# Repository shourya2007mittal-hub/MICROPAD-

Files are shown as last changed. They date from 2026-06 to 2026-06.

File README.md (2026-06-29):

# MICROPAD-



I  built a updated macro pad with 9 switches an 0.91 inch Display , a rotor encoder through which I can change between the layers and one RGB LED per switch , It will be  use wireless connection and will use Xiao nrf52840 as the main microcontroller.

## Features

- Base on Xiao NRF Module
- Has per switch LED
- Works wirelessly and has a Battery built in
- Has 9 Switch and 3 Different Layers to switch onto

# Bill of Materials (BOM)

This document contains the list of all components required for the project, including quantities, estimated prices, and direct purchase links.

## Components

| Item | Quantity | Price (USD) | Purchase Link |
|---|---|---:|---|
| PCB + Shipping | - | 18.72 | https://jlcpcb.com |
| SK6812 Mini-E RGB | 1 Pack | 13.19 | https://www.desertcart.in/products/713547616-50pcs-sk6812-mini-e-rgb-similar-with-ws2812b-sk6812-3228 |
| Mini SPDT Slide Switch (+ Shipping) | Pack of 3 | 1.64 | https://www.amazon.in/gp/product/B0B434R6QF/ref=ox_sc_act_image_1?smid=A2JDRZEGU1IDE2&psc=1 |
| Blank DSA Keycaps | 2 Sets of 5 | 2.00 | https://meckeys.com/shop/accessories/keyboard-accessories/keycaps/blank/blank-dsa-keycaps-1u/ |
| Kailh Hot-Swap Sockets | 2 Packs of 5 | 1.65 | https://meckeys.com/shop/accessories/keyboard-accessories/key-switches/kailh-hot-swap-socket/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 |
| Gateron Optical Switches | 1 Pack of 10 | 4.50 | https://meckeys.com/shop/accessories/keyboard-accessories/key-switches/gateron-optical-switch-pack/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 |
| Meckeys Shipping | - | 1.10 | https://meckeys.com |
| 450mAh 3.7V LiPo Battery | 1 | 1.70 | https://robocraze.com/products/450mah-3-7v-lipo-rechargeable-battery?variant=51440287219936 |
| Rotary Encoder Module | 1 | 0.69 | https://robocraze.com/products/rotary-encoder-module?variant=40193048543385 |
| 0.91" OLED Display Module | 1 | 1.58 | https://robocraze.com/products/0-91-inch-blue-oled-display-module?variant=40194383413401 |
| Seeed Studio XIAO nRF52840 | 1 | 12.16 | https://robocraze.com/products/seeed-studio-xiao-nrf52840-development-board-supports-bluetooth-5-0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 |

## Estimated Cost

| Description | Amount (USD) |
|---|---:|
| **Total Estimated Cost** | **58.93** |

### Schematic



###  PCB Design




### 3D Design





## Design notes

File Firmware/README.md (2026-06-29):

# XIAO nRF52840 3-Layer Macropad Firmware

## Pin Allocation (From Schematic)
- **Rows:** R1 -> D0, R2 -> D1, R3 -> D2
- **Columns:** C1 -> D3, C2 -> D6, C3 -> D8
- **I2C Display:** SDA -> D4, SCL -> D5
- **Encoder:** A1 -> D9, B1 -> D10
- **LED Indicator:** LED -> D5 (Shared pin configuration)

## Features
1. **Boot Mode Condition:** Hold down Key 1 (Row 1, Column 1) during startup to enter **Input Device Mode** (USB HID Keyboard). Powering on without holding the key sets it to **Output Device Mode**.
2. **Layer Switching:** Turn the rotary encoder to cycle seamlessly through 3 structural key layers.
3. **OLED Status:** Displays the current operating mode and active layer in real-time.

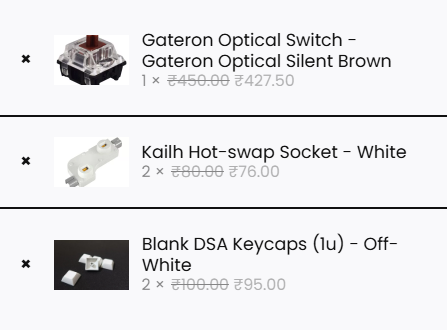
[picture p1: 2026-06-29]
Screen-Shot/Screenshot 2026-06-30 000758.png

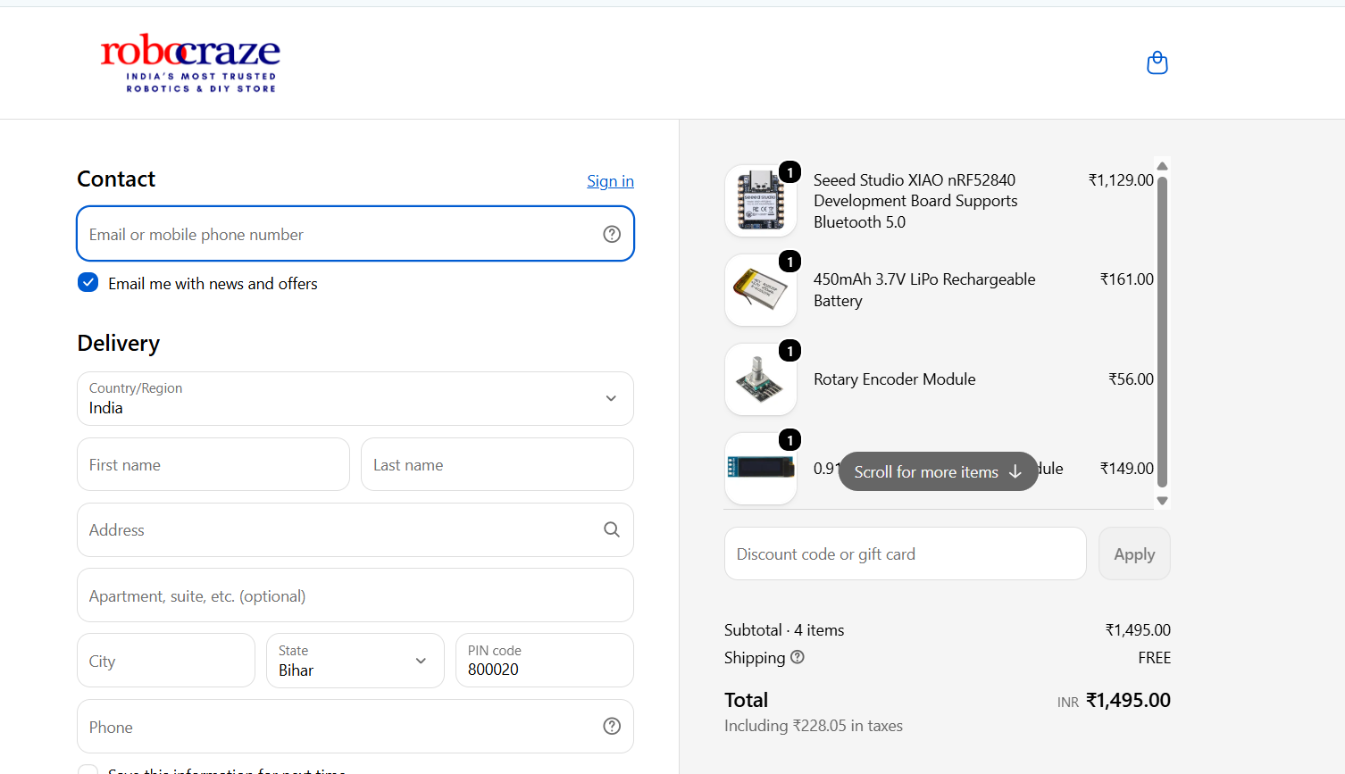
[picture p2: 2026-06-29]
Screen-Shot/Screenshot 2026-06-30 002320.png

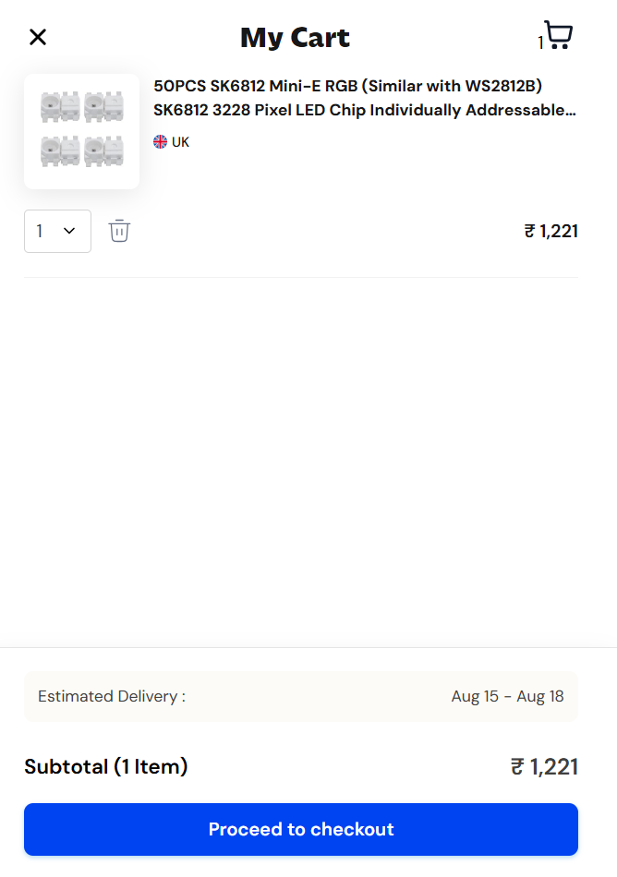
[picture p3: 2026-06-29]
Screen-Shot/Screenshot 2026-06-30 001117.png

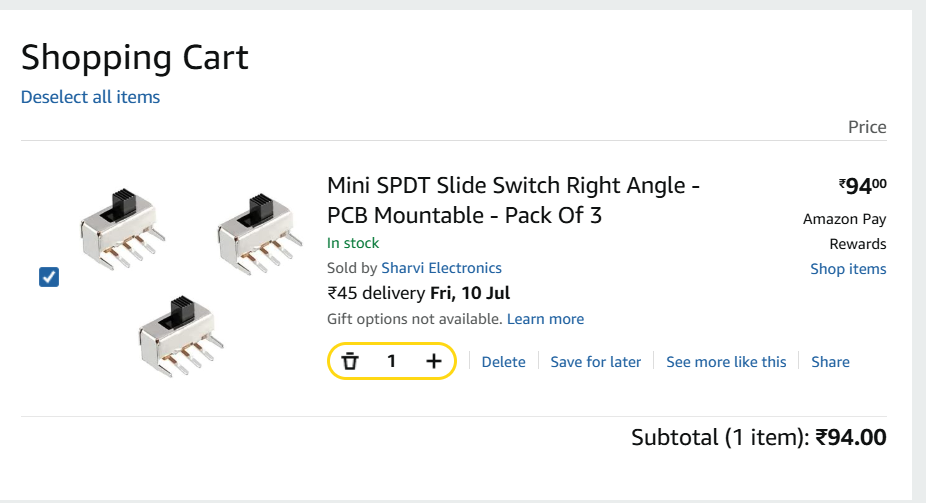
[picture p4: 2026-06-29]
Screen-Shot/Screenshot 2026-06-30 000644.png

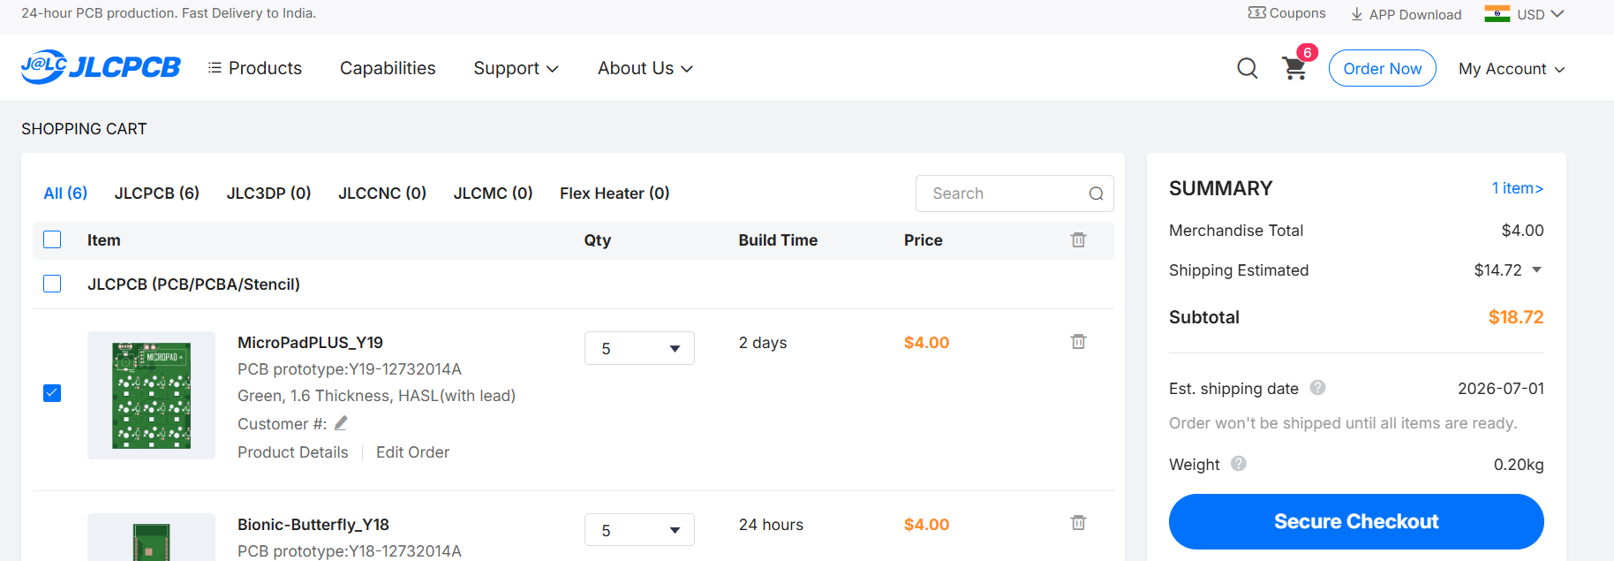
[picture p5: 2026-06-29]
Screen-Shot/Screenshot 2026-06-29 235157.png

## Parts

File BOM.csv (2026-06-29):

Item | Quantity | Price | Source
PCB + Shipping | - | 4+14.72=18.72 | JLCPCB
SK6812 Mini-E RGB | 1 PACK | 13.19 | https://www.desertcart.in/products/713547616-50pcs-sk6812-mini-e-rgb-similar-with-ws2812b-sk6812-3228
Mini SPDT Slide Switch + shipping | Pack of (3) | 1.64 | https://www.amazon.in/gp/product/B0B434R6QF/ref=ox_sc_act_image_1?smid=A2JDRZEGU1IDE2&psc=1
Keycaps | 2 set of 5 | 2 | https://meckeys.com/shop/accessories/keyboard-accessories/keycaps/blank/blank-dsa-keycaps-1u/
Hot-swap | 2 Pack of 5 | 1.65 | https://meckeys.com/shop/accessories/keyboard-accessories/key-switches/kailh-hot-swap-socket/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
Switch | 1 Pack of 10 | 4.5 | https://meckeys.com/shop/accessories/keyboard-accessories/key-switches/gateron-optical-switch-pack/
Meckeys shipping | - | 1.1 | meckey.com
450mAh 3.7V LiPo Battery | 1 | 1.7 | https://robocraze.com/products/450mah-3-7v-lipo-rechargeable-battery?variant=51440287219936
Rotary Encoder | 1 | .69 | https://robocraze.com/products/rotary-encoder-module?variant=40193048543385
0.91 inch OLED Screen | 1 | 1.58 | https://robocraze.com/products/0-91-inch-blue-oled-display-module?variant=40194383413401
Seeed Studio XIAO nRF52840 | 1 | 12.16 | https://robocraze.com/products/seeed-studio-xiao-nrf52840-development-board-supports-bluetooth-5-0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

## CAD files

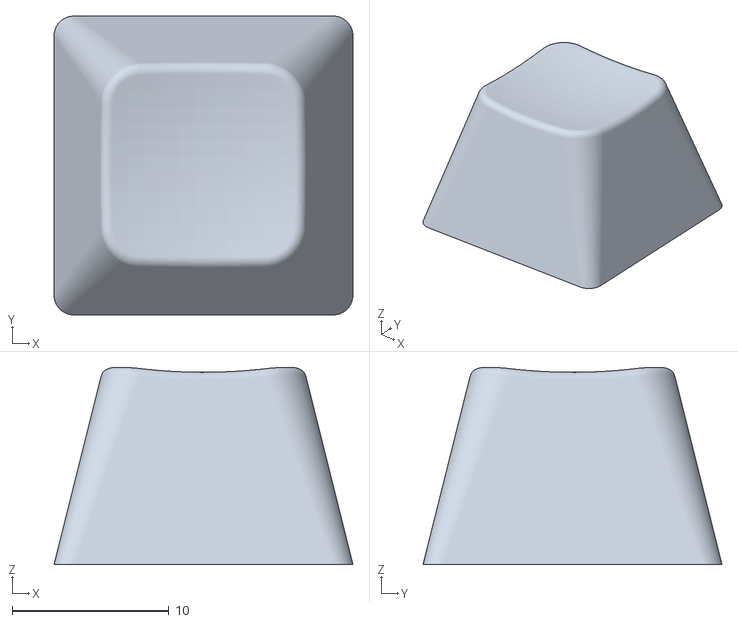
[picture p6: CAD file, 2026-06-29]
Production/CAD/KeyCap.stl
19.0 x 19.0 x 12.6

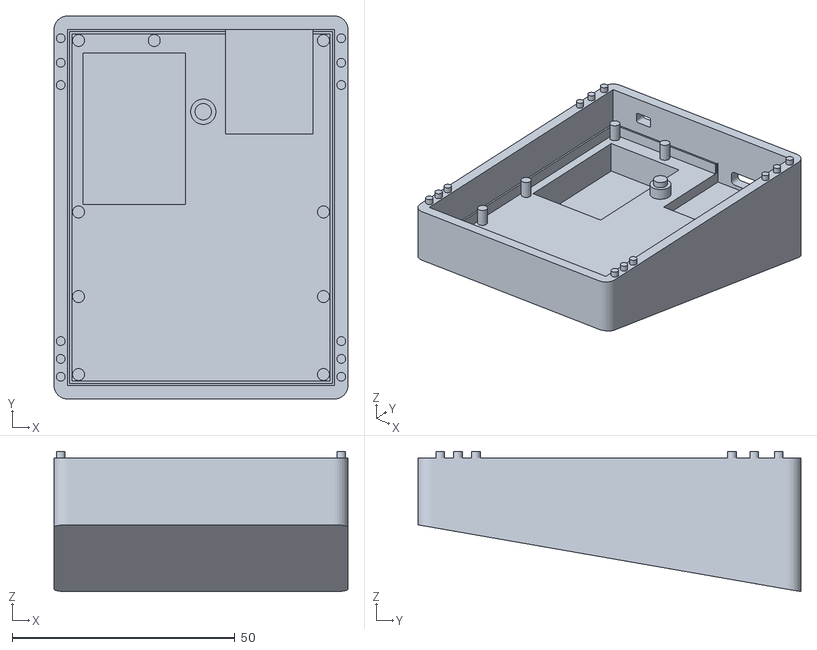
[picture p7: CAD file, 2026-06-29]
Production/CAD/Bottom-Base.stl
66.0 x 86.0 x 31.5

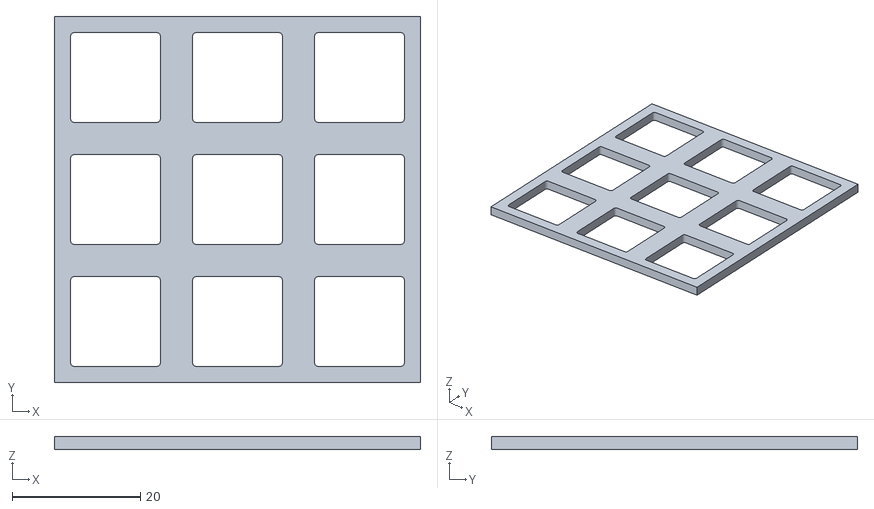
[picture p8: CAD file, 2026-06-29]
Production/CAD/Switch Holder.stl
57.1 x 57.1 x 2.00

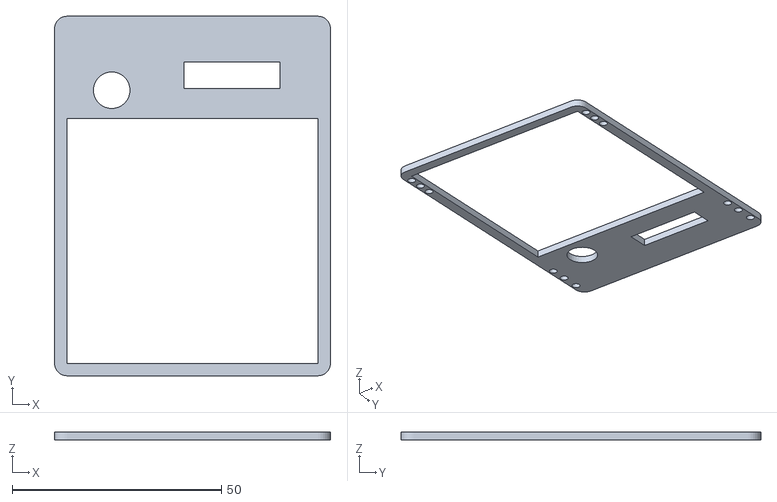
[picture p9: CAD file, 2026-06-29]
Production/CAD/Top-Cover.stl
66.0 x 86.0 x 2.00

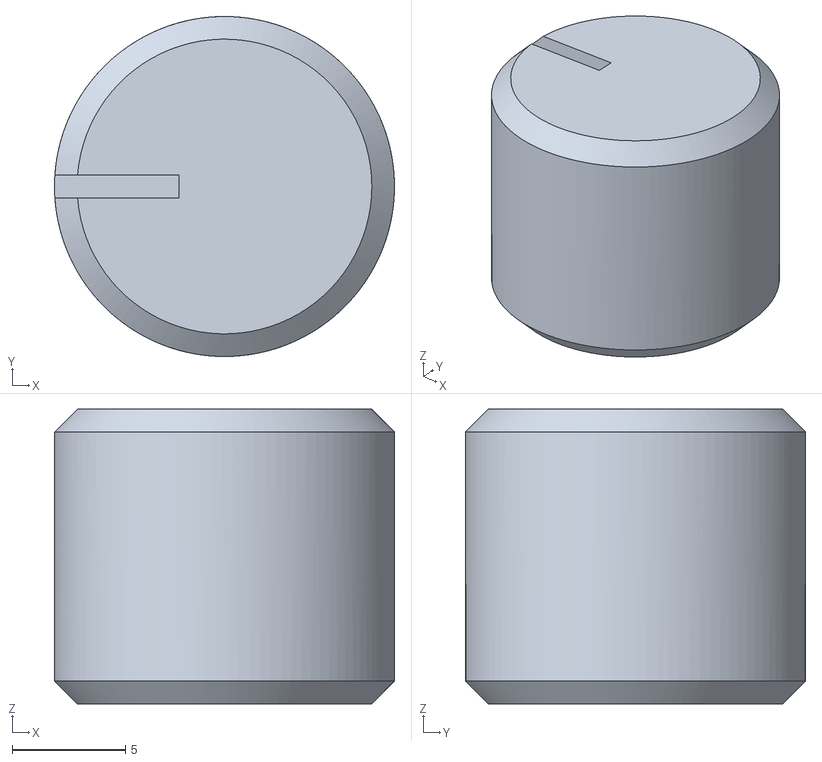
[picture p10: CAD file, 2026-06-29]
Production/CAD/rotarydial.stl
15.0 x 15.0 x 13.0

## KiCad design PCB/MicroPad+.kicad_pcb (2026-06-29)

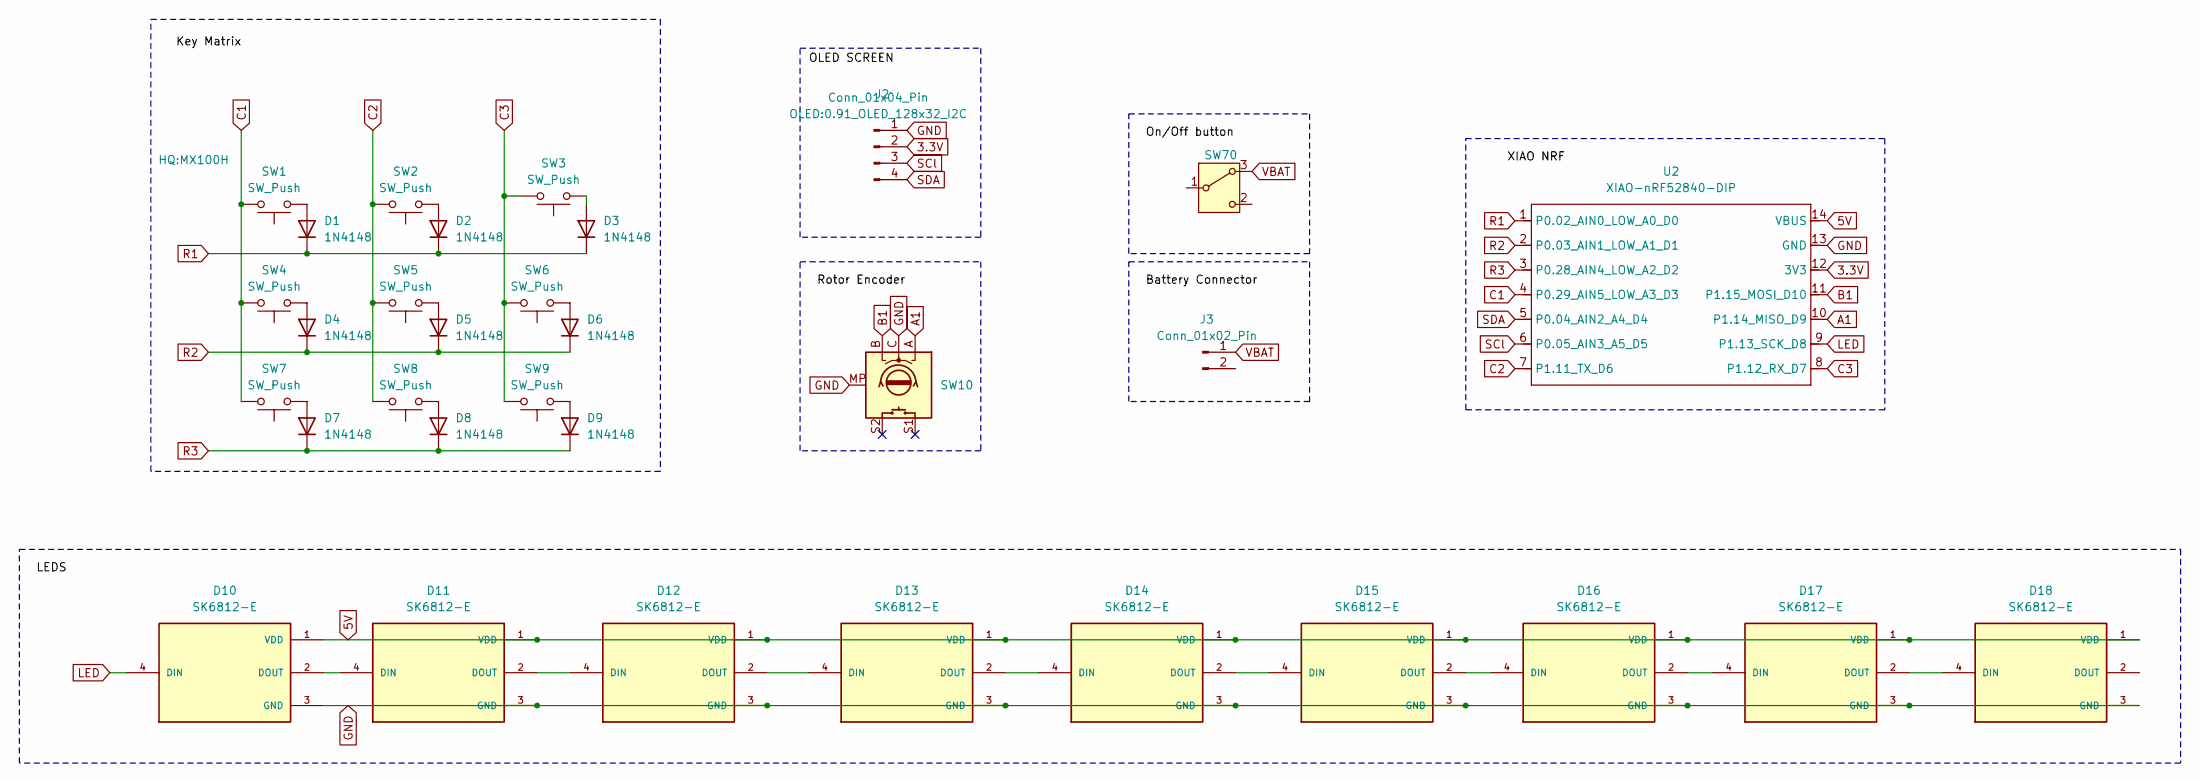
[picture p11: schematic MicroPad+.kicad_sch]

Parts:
D1, D2, D3, D4, D5, D6, D7, D8, D9: 1N4148; D_DO-35_SOD27_P7.62mm_Horizontal
D10, D11, D12, D13, D14, D15, D16, D17, D18: SK6812-E; LED_SK6812-E; PARTREV 2
J2: Conn_01x04_Pin; 0.91_OLED_128x32_I2C
J3: Conn_01x02_Pin; AMASS_XT30U-F_1x02_P5.0mm_Vertical
SW1, SW2, SW3, SW4, SW5, SW6, SW7, SW8, SW9: SW_Push; MX100H
SW10: RotaryEncoder_Switch_MP; RotaryEncoder_Alps_EC11E-Switch_Vertical_H20mm
SW70: SW_Wuerth_450301014042; SW_Slide_SPDT_Angled_CK_OS102011MA1Q
U2: XIAO-nRF52840-DIP; XIAO-nRF52840-SMD

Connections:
3.3V: J2.2, U2.12 (3V3)
5V: D10.1 (VDD), D11.1 (VDD), D12.1 (VDD), D13.1 (VDD), D14.1 (VDD), D15.1 (VDD), D16.1 (VDD), D17.1 (VDD), D18.1 (VDD), U2.14 (VBUS)
A1: SW10.A, U2.10 (P1.14_MISO_D9)
B1: SW10.B, U2.11 (P1.15_MOSI_D10)
C1: SW1.2, SW4.2, SW7.2, U2.4 (P0.29_AIN5_LOW_A3_D3)
C2: SW2.2, SW5.2, SW8.2, U2.7 (P1.11_TX_D6)
C3: SW3.2, SW6.2, SW9.2, U2.8 (P1.12_RX_D7)
GND: D10.3 (GND), D11.3 (GND), D12.3 (GND), D13.3 (GND), D14.3 (GND), D15.3 (GND), D16.3 (GND), D17.3 (GND), D18.3 (GND), J2.1, SW10.C, SW10.MP, U2.13 (GND)
LED: D10.4 (DIN), U2.9 (P1.13_SCK_D8)
unnamed: D1.2 (A), SW1.1
unnamed: D2.2 (A), SW2.1
unnamed: D3.2 (A), SW3.1
unnamed: D4.2 (A), SW4.1
unnamed: D5.2 (A), SW5.1
unnamed: D6.2 (A), SW6.1
unnamed: D7.2 (A), SW7.1
unnamed: D8.2 (A), SW8.1
unnamed: D9.2 (A), SW9.1
unnamed: D10.2 (DOUT), D11.4 (DIN)
unnamed: D11.2 (DOUT), D12.4 (DIN)
unnamed: D12.2 (DOUT), D13.4 (DIN)
unnamed: D13.2 (DOUT), D14.4 (DIN)
unnamed: D14.2 (DOUT), D15.4 (DIN)
unnamed: D15.2 (DOUT), D16.4 (DIN)
unnamed: D16.2 (DOUT), D17.4 (DIN)
unnamed: D17.2 (DOUT), D18.4 (DIN)
R1: D1.1 (K), D2.1 (K), D3.1 (K), U2.1 (P0.02_AIN0_LOW_A0_D0)
R2: D4.1 (K), D5.1 (K), D6.1 (K), U2.2 (P0.03_AIN1_LOW_A1_D1)
R3: D7.1 (K), D8.1 (K), D9.1 (K), U2.3 (P0.28_AIN4_LOW_A2_D2)
SCl: J2.3, U2.6 (P0.05_AIN3_A5_D5)
SDA: J2.4, U2.5 (P0.04_AIN2_A4_D4)
VBAT: J3.1, SW70.3 (A)

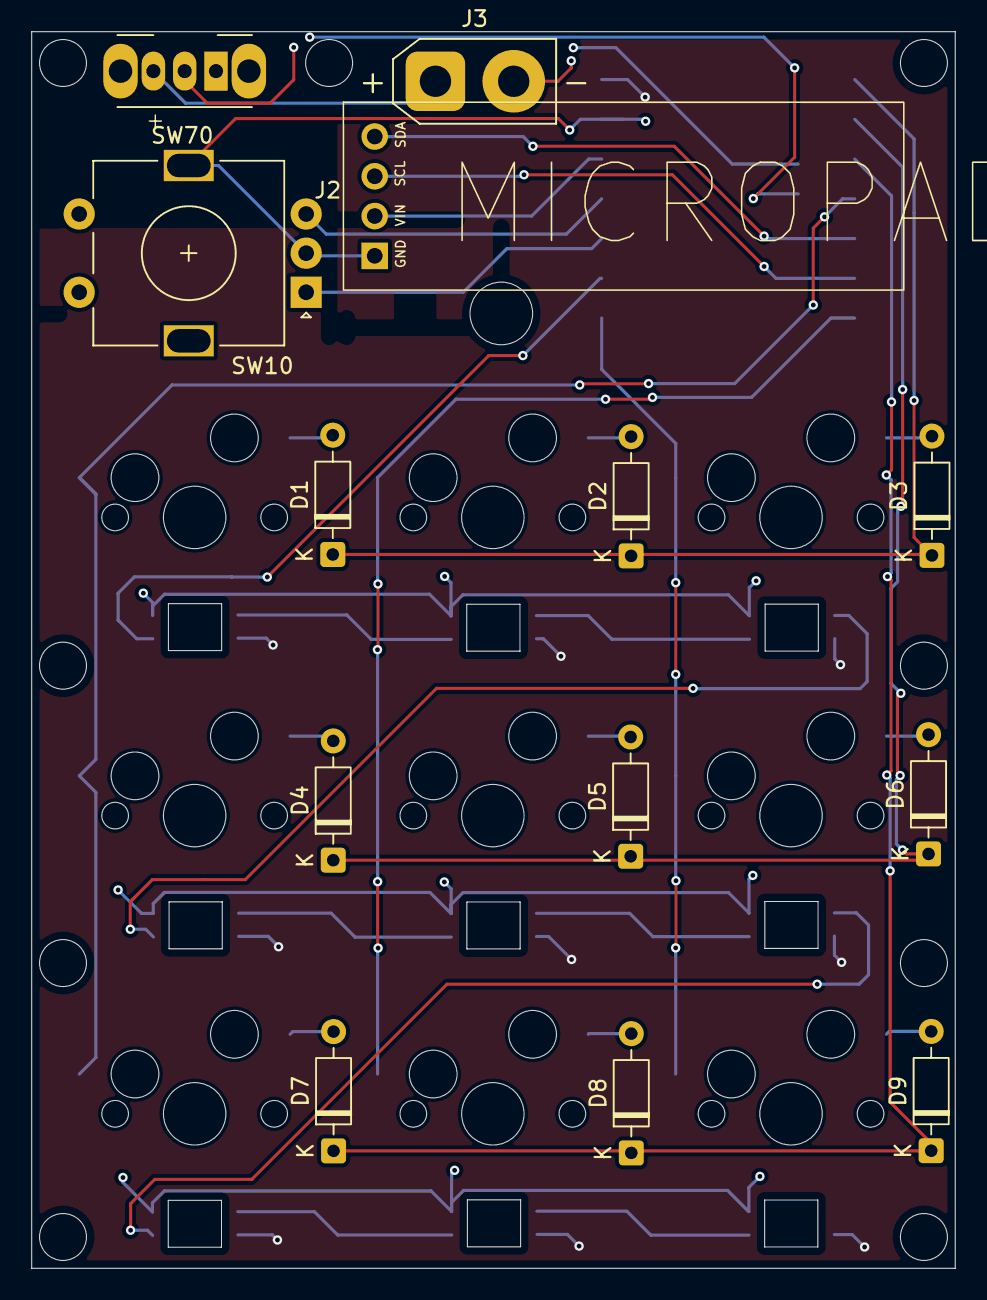
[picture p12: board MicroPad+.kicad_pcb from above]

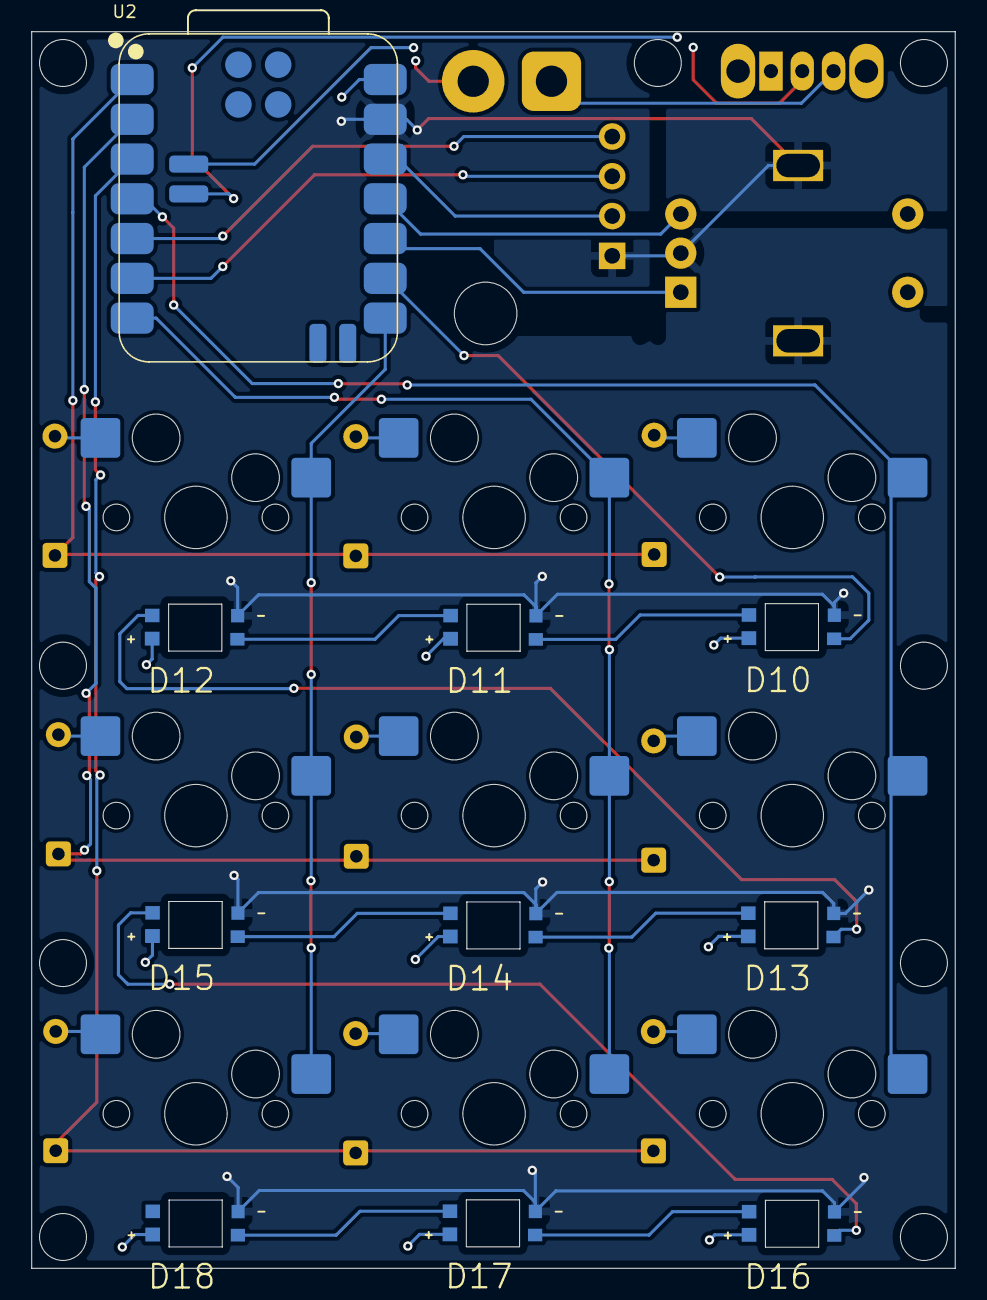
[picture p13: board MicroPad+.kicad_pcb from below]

Board: 2 copper layers, 59.0 x 79.0 mm, 32 parts (19 on the bottom side), 32 nets.

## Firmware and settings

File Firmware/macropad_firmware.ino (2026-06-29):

#include <Wire.h>
#include <Adafruit_GFX.h>
#include <Adafruit_SSD1306.h>
#include <RotaryEncoder.h>
#include <PluggableUSBHID.h>
#include <USBKeyboard.h>

// --- OLED Display Configuration ---
#define SCREEN_WIDTH 128
#define SCREEN_HEIGHT 32
#define OLED_RESET    -1
Adafruit_SSD1306 display(SCREEN_WIDTH, SCREEN_HEIGHT, &Wire, OLED_RESET);

// --- Pin Definitions from Schematic ---
// Matrix Rows & Columns
const int rowPins[3] = {D0, D1, D2}; // R1=D0, R2=D1, R3=D2
const int colPins[3] = {D3, D6, D8}; // C1=D3, C2=D6, C3=D8

// Rotary Encoder Pins
#define ENCODER_PIN_A D9   // A1 mapped to D9 (P1.14_MISO_D9)
#define ENCODER_PIN_B D10  // B1 mapped to D10 (P1.15_MOSI_D10)

// Debug Status LED
#define STATUS_LED D5      // LED mapped to D5 (P0.05_AIN3_A5_D5)

// --- Operating Modes ---
enum DeviceMode { OUTPUT_MODE, INPUT_MODE };
DeviceMode currentMode = OUTPUT_MODE;

// --- Layer Configuration ---
int currentLayer = 0;
const int TOTAL_LAYERS = 3;

// Keymap definitions for INPUT MODE (USB HID Keyboard layout)
const char keymaps[TOTAL_LAYERS][3][3] = {
  { // Layer 0: Media / Navigation
    {'1', '2', '3'},
    {'4', '5', '6'},
    {'7', '8', '9'}
  },
  { // Layer 1: Numpad / Custom
    {'a', 'b', 'c'},
    {'d', 'e', 'f'},
    {'g', 'h', 'i'}
  },
  { // Layer 2: Macro Shortcuts
    {'X', 'Y', 'Z'},
    {'+', '-', '*'},
    {'[', ']', '='}
  }
};

// Track key states to prevent duplicate presses
bool lastKeyState[3][3] = { {false, false, false}, {false, false, false}, {false, false, false} };

// Setup Rotary Encoder
RotaryEncoder encoder(ENCODER_PIN_A, ENCODER_PIN_B, RotaryEncoder::LatchMode::FOUR3);
USBKeyboard Keyboard; // Instantiated for HID functionality

void updateDisplay() {
  display.clearDisplay();
  display.setTextSize(1);
  display.setTextColor(SSD1306_WHITE);
  
  // Display current active system mode
  display.setCursor(0, 0);
  display.print("MODE: ");
  if (currentMode == INPUT_MODE) {
    display.print("USB KEYBOARD (IN)");
  } else {
    display.print("PERIPHERAL (OUT)");
  }
  
  // Display active functional layer
  display.setCursor(0, 16);
  display.setTextSize(2);
  display.print("LAYER: ");
  display.print(currentLayer + 1);
  
  display.display();
}

void checkBootMode() {
  // Boot Code rule: Check if Top-Left Matrix button (R1, C1) is held at startup
  pinMode(rowPins[0], OUTPUT);
  digitalWrite(rowPins[0], LOW); // Set Row 1 active
  
  pinMode(colPins[0], INPUT_PULLUP); // Read Column 1
  delay(50); // Small debounce window
  
  if (digitalRead(colPins[0]) == LOW) {
    currentMode = INPUT_MODE; // Switched on and pressing a button -> Input Device
  } else {
    currentMode = OUTPUT_MODE; // Default -> Output Device
  }
  
  // Reset pins back to default states
  digitalWrite(rowPins[0], HIGH);
}

void setup() {
  // Initialize Status LED
  pinMode(STATUS_LED, OUTPUT);
  digitalWrite(STATUS_LED, HIGH); // Off (XIAO LEDs are usually active-low)

  // Initialize Matrix Pins
  for (int i = 0; i < 3; i++) {
    pinMode(rowPins[i], OUTPUT);
    digitalWrite(rowPins[i], HIGH);
    pinMode(colPins[i], INPUT_PULLUP);
  }

  // Evaluate startup boot conditions
  checkBootMode();

  // Initialize OLED Display via standard I2C (SDA=D4, SCL=D5 as per schematic context)
  if(!display.begin(SSD1306_SWITCHCAPVCC, 0x3C)) { 
    // Blink LED rapidly if display connection fails
    while(1) {
      digitalWrite(STATUS_LED, LOW); delay(100);
      digitalWrite(STATUS_LED, HIGH); delay(100);
    }
  }
  
  updateDisplay();
}

void loop() {
  // 1. Read Rotary Encoder to change Active Layers
  encoder.tick();
  int newPos = (int)encoder.getDirection();
  if (newPos != 0) {
    currentLayer += (int)newPos;
    if (currentLayer >= TOTAL_LAYERS) currentLayer = 0;
    if (currentLayer < 0) currentLayer = TOTAL_LAYERS - 1;
    updateDisplay();
  }

  // 2. Scan Key Matrix
  for (int r = 0; r < 3; r++) {
    digitalWrite(rowPins[r], LOW); // Activate active row
    
    for (int c = 0; c < 3; c++) {
      bool isPressed = (digitalRead(colPins[c]) == LOW);
      
      if (isPressed && !lastKeyState[r][c]) {
        // --- KEY DOWN EVENT ---
        if (currentMode == INPUT_MODE) {
          // Act as USB Input Device
          Keyboard.key_code(keymaps[currentLayer][r][c]);
        } else {
          // Act as Output Device (Example: Debug print over Serial, or MIDI commands)
          digitalWrite(STATUS_LED, LOW); // Pulse active LED indicator on active output
        }
        lastKeyState[r][c] = true;
        delay(10); // Debounce
      } 
      else if (!isPressed && lastKeyState[r][c]) {
        // --- KEY UP EVENT ---
        if (currentMode == OUTPUT_MODE) {
          digitalWrite(STATUS_LED, HIGH);
        }
        lastKeyState[r][c] = false;
        delay(10); // Debounce
      }
    }
    digitalWrite(rowPins[r], HIGH); // Deactivate row
  }
}
